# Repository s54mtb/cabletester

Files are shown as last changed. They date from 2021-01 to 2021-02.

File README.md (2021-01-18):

# cabletester, simple cable testing tool

This is simple cable testing tool for checking your cables (e.g. ethernet patch cables or house installation).  Complete tester consists of two modules and tested cable. Master (left) module is on the left. It is connected to the power supply (battery or wall adapter). Slave (right) is passive and has only LEDs. 
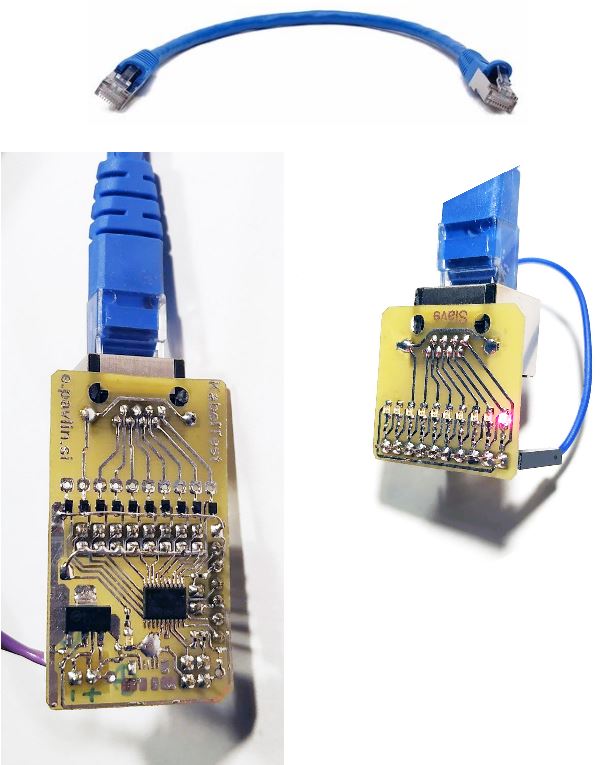
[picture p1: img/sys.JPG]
Cable tester


If cable is OK, the leds should run in ordered sequence: 
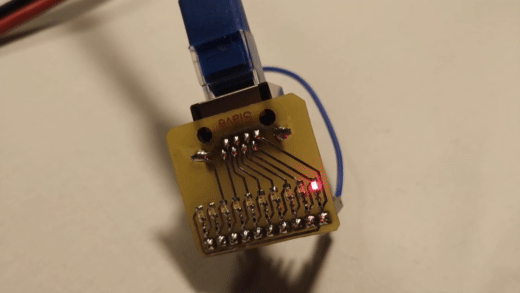
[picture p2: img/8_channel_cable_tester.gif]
LED Sequence


Youtube video: https://youtu.be/-cTYe7WnijU

## Hardware
[Assembly instructions](https://github.com/s54mtb/cabletester/blob/main/HW/AssemblyInstr.md)

### Schematic
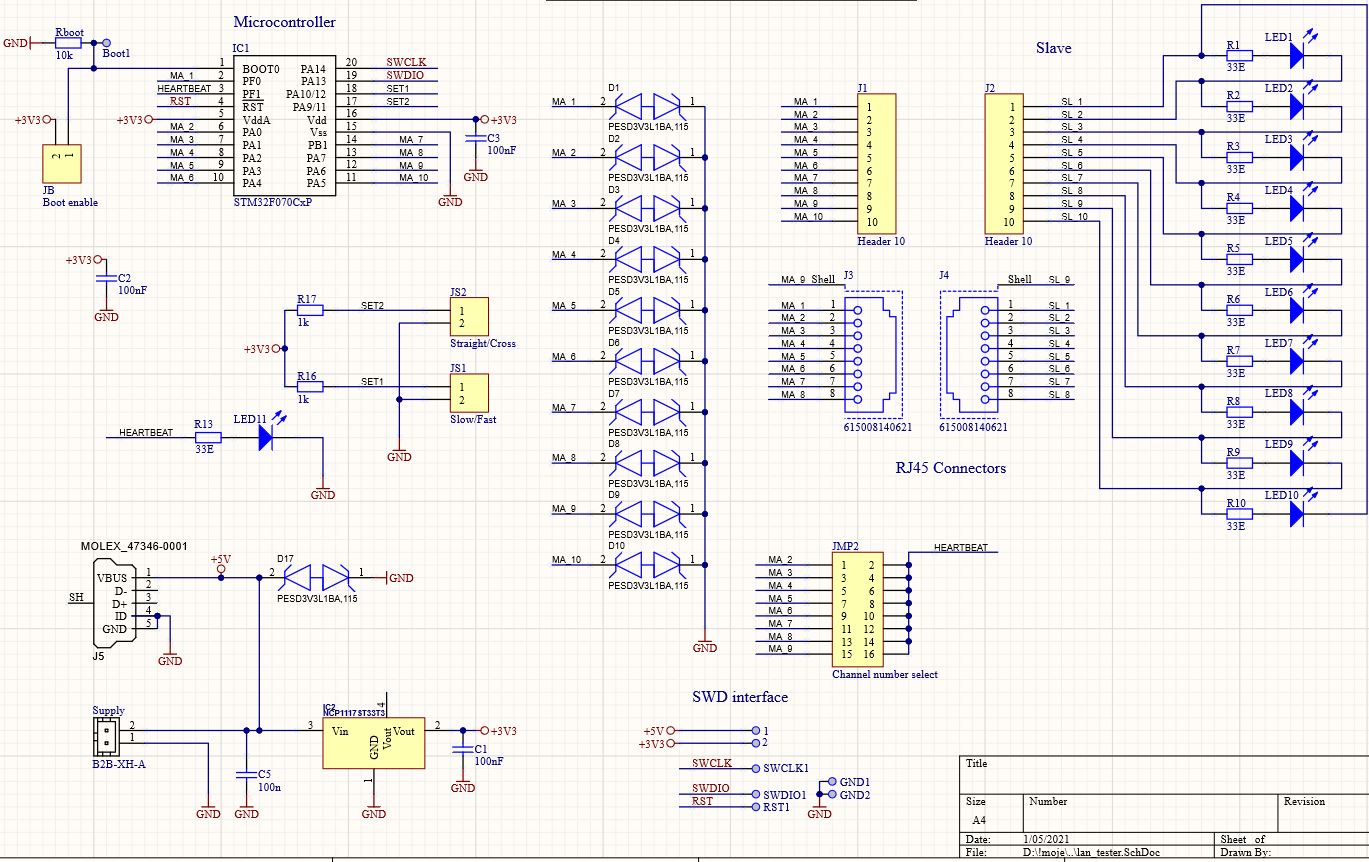
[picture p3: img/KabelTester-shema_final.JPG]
Cable tester schematic


### PCB
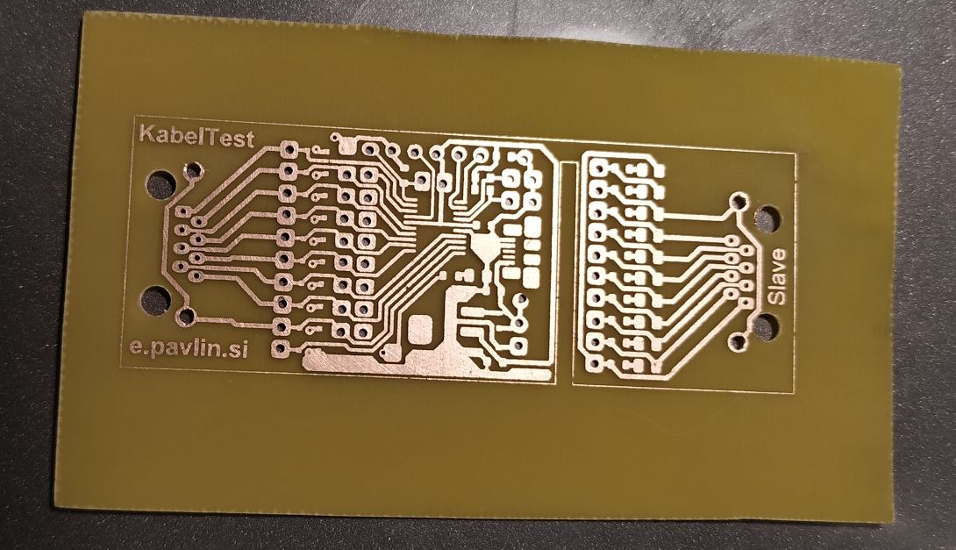
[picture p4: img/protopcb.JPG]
Cable tester single sided PCB


### Artwork for toner transfer PCB
PDF for home made PCB with toner transfer (multiple and single PCB) is available [here](https://github.com/s54mtb/cabletester/blob/main/img/Lantester-tonertransfer.pdf).

## Software
Initial project is prepared with free keil uVision for stm32f0 family.

### Downloading firmware
There is no need to use any IDE or programming adapter to download the firmware. It can be done via serial bootloader. Detailed instructions [are here](https://github.com/s54mtb/cabletester/blob/main/SW/FWdownload.md).

## Housing
Work in progress.

## Operation
There are several jumpers available to control operation of the tester. 

### JS1 - Speed
JS1 selects the speed of sequence. When jumper is attached, the sequence is slow or fast when removed:
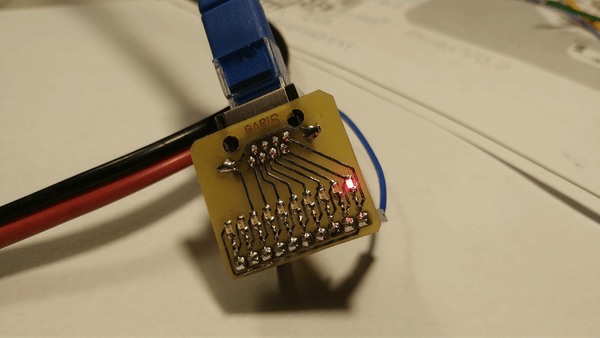
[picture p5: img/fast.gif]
Fast sequence


### JS2 - Cross/straight
JS2 select sequence: When not present the sequence is "normal": Ch1, Ch2, ... Chn. When Jumper is present, the sequnence is set for cross linked cable (useful for testing crosslink patch cables). 

### JMP2 - Channel selection
The cable tester has 10 channels. The channel sequence can ruun from 2 to maximum 10 channels. Jumper JMP2 defines number of channels. Inserted jumper bridge defines where the sequence will stop. When bridge is inserted between pins 13 and 14 (Channel 8), the sequence will run up to 8th channel. Example of the sequence when jumper is placed on channel 5: 

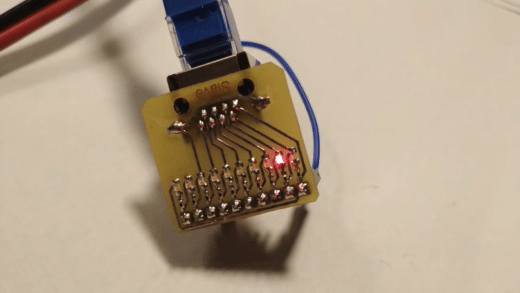
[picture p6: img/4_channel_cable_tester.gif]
5 channels enabled


### Slave settings
PCB for slave device is prepared for RJ45 female connector. There are 10 pins for custom connectors available. When testing less than 10 wires, a jumper must be placed between last+1 channel and first channel to provide proper connection for LEDs.

Example for testing ethernet patch cable (8 channels active): jumper should be placed between pin 1 and pin 9 on the jumper J4 (slave device): 

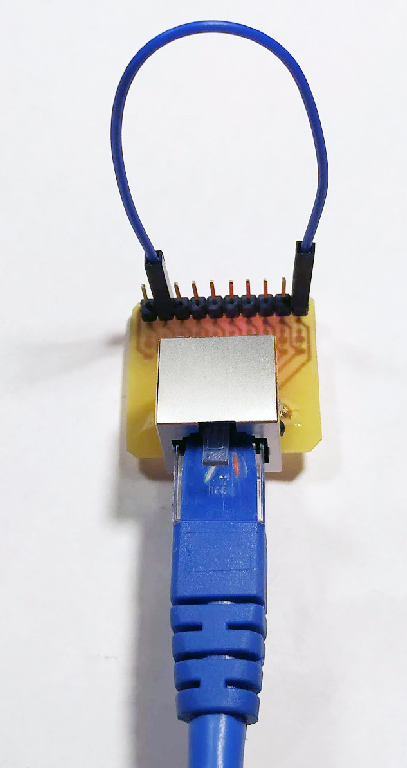
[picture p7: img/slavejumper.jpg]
SlaveJumper


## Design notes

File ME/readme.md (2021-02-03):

# 3D printed housing for this project

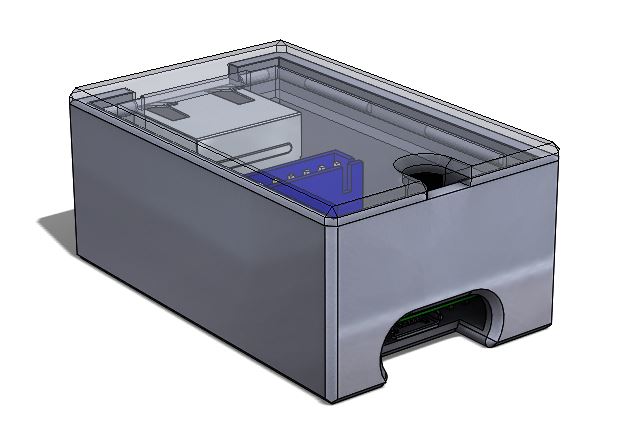
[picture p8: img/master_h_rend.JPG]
Master housing

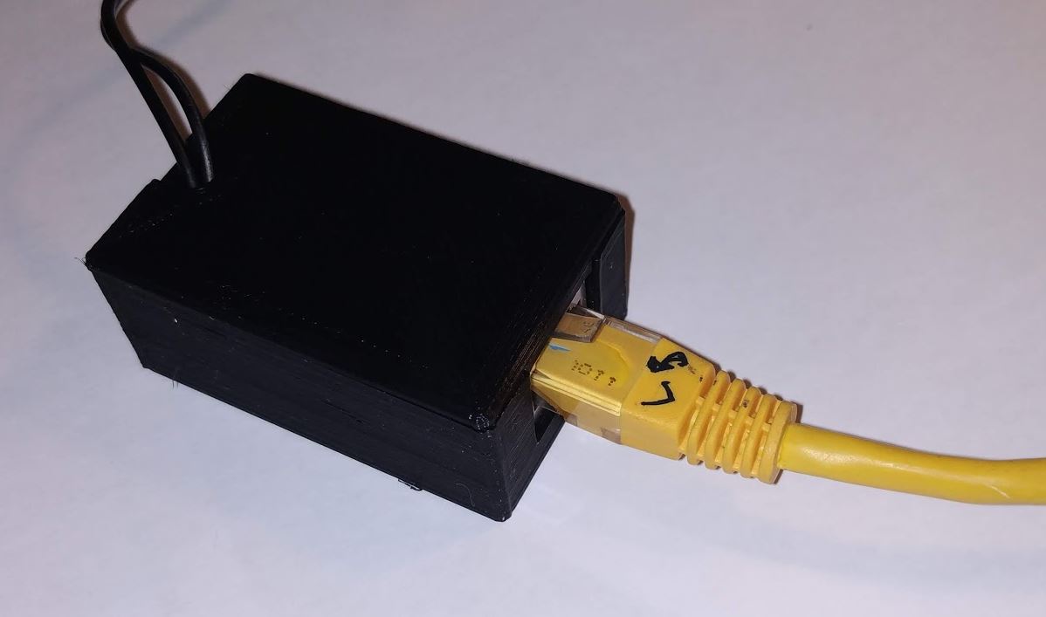
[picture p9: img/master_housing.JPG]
Master housing


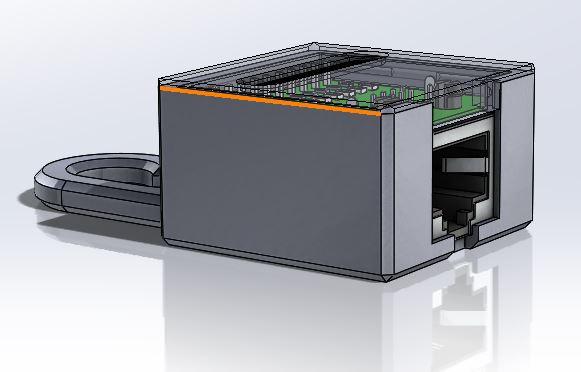
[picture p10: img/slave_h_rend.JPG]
Slave housing

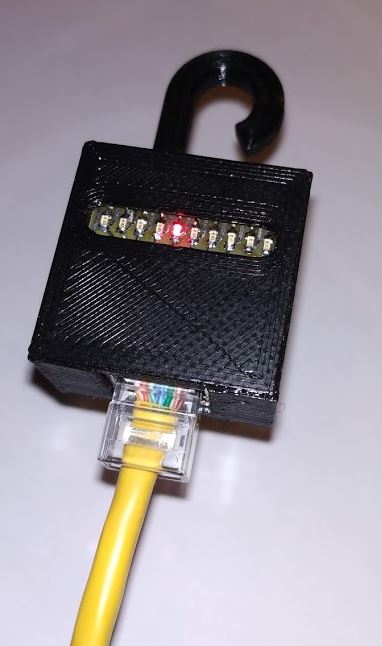
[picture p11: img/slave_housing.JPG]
Slave housing


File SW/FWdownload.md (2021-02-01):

# Downloading firmware
Cable tester has jumpers to enable the bootloader. There is no on-board hardware for downloading the firmware (like arduino) to keep the cost of the device down. 

## Required tools

### Hardware
USB to UART interface is required tool for downloading the firmware. Just make surte it has 3,3V levels. Something like this works fine:

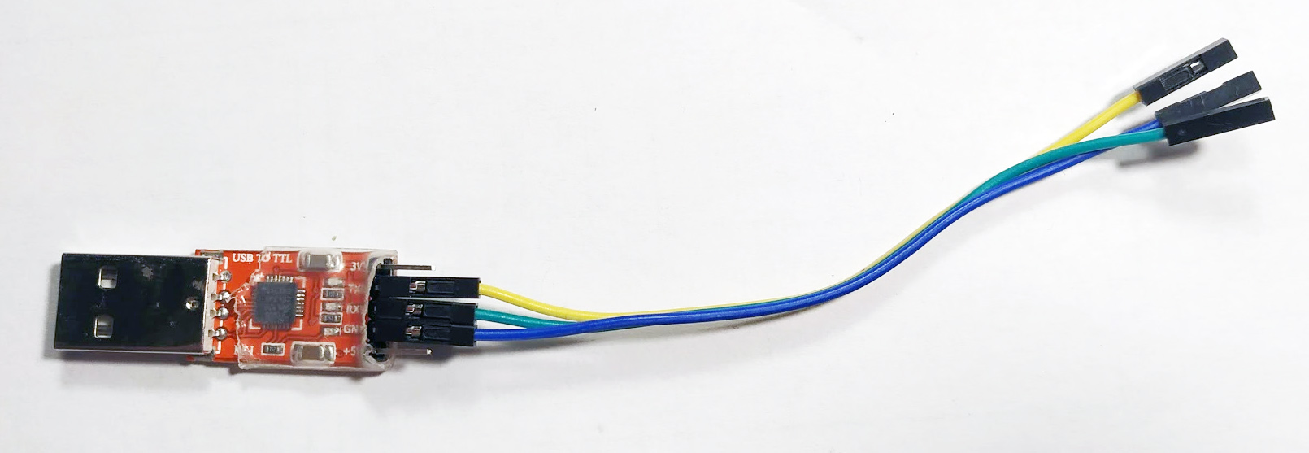
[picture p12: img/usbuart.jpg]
USB to UART interface


### Software
Install STM flash loader demonstrator:  https://www.st.com/en/development-tools/flasher-stm32.html

## Procedure

Remove power supply. Remove all jumpers if placed. 

### Enable bootloader
Place only JB jumper to enable bootloader. 

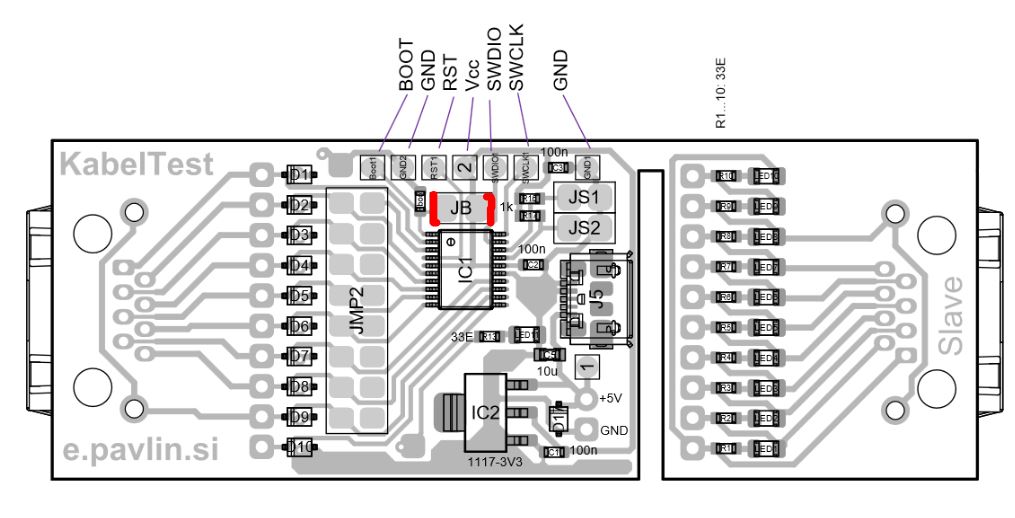
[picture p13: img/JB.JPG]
JB jumper


### Connect serial interface
Three connections are required between USB/UART interface and cable tester: 

* Blue wire: GND
* Green wire (Rx un USB/UART interface), connect to JS2 (PA9/PA11)
* Yellow wire (Tx on USB/UART interface), connect to JS1 (PA10/PA12)

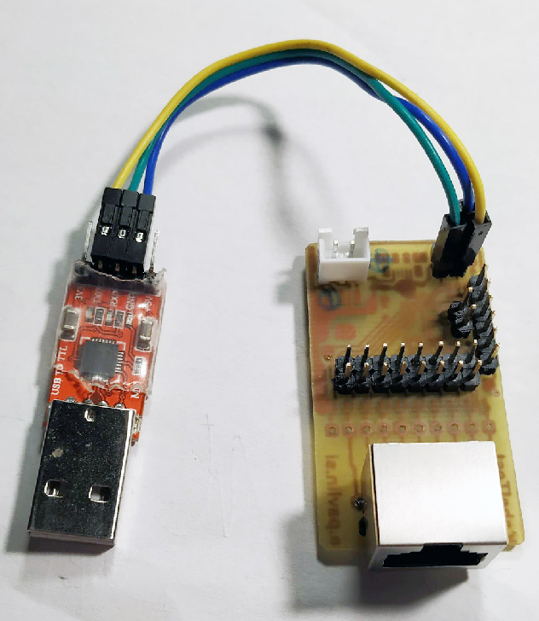
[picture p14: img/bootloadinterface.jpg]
serial connection


Now power-up the circuit and connect serial interface to USB port. 

### Load the software
Run the installed STM32 flasher demonstrator. Select the UART interface: 

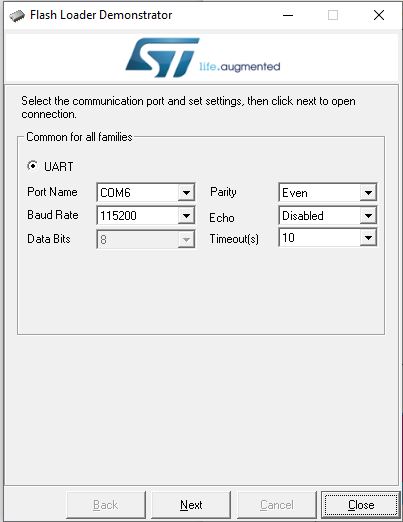
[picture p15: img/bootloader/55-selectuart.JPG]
Select uart


If all is connected and powered up correctly, the application should notice "Target readable": 

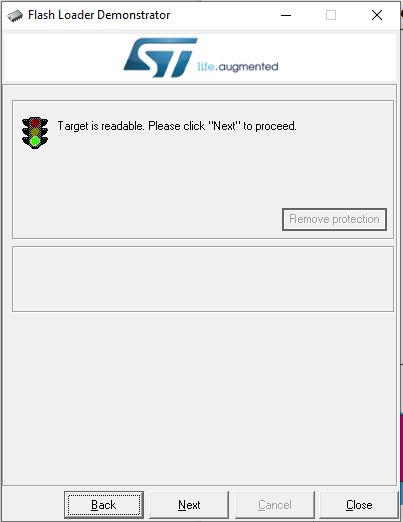
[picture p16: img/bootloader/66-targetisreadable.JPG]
Target readable


Now select the target device: 

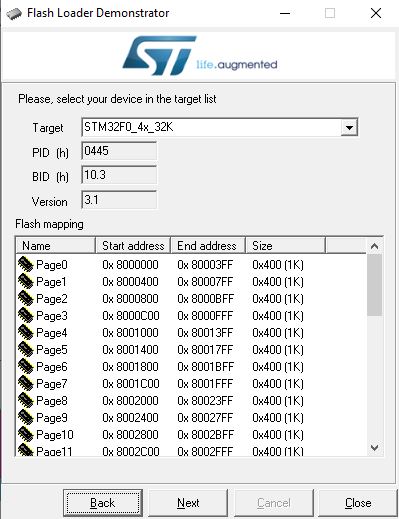
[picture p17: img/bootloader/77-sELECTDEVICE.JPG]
Target device


Select the option "Download to device". Next, select [the hex file](https://raw.githubusercontent.com/s54mtb/cabletester/main/SW/Objects/cabltestr10.hex): 

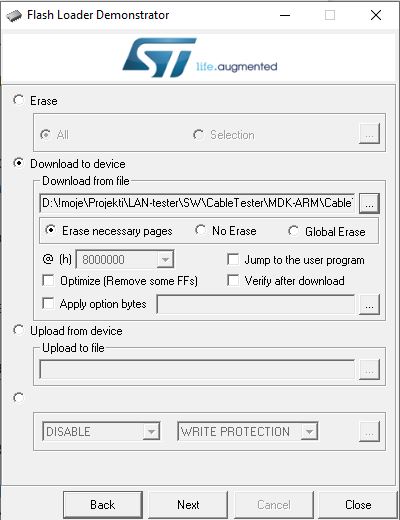
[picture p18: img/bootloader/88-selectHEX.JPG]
Select hex


Hit button "Next". The programming should finish successfully with the notice: 

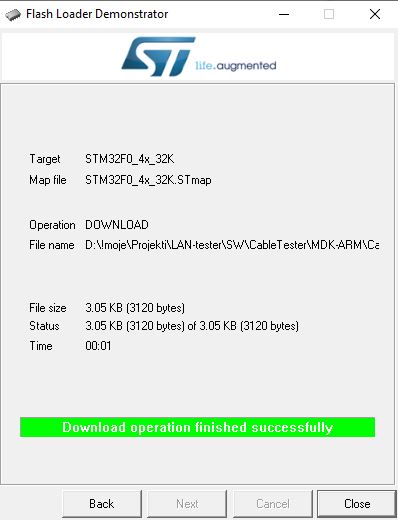
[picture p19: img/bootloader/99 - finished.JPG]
Finished


## Finalize

Remove power from the device. 

Remove jumper JB and UART interface. Place jumper to select the number of channels. 

Power the device, connect the cable and test the operation. 

# Alternative

Use ST-link (integrated on nucleo or discovery board or stand-alone) or any other SWD interface to program via SWD interface. The pinout is shown above. I tested with ST-link, nucleo and U-Link interface with success.

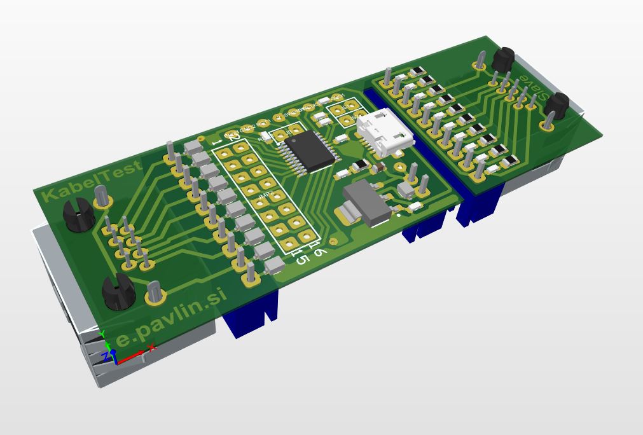
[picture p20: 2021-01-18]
img/pcb-top.JPG

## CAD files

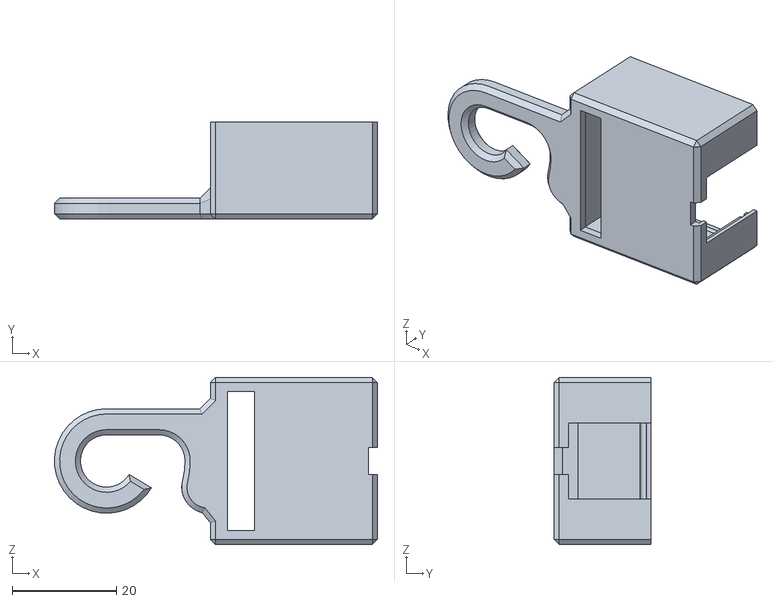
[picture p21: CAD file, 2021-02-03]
ME/slave_bot.STL
61.8 x 18.6 x 32.0

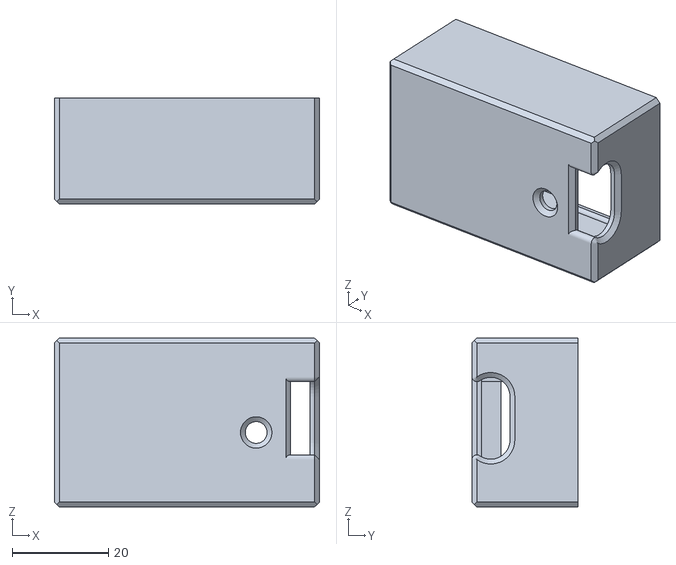
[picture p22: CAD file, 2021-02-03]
ME/master_bot.STL
55.0 x 22.0 x 35.0

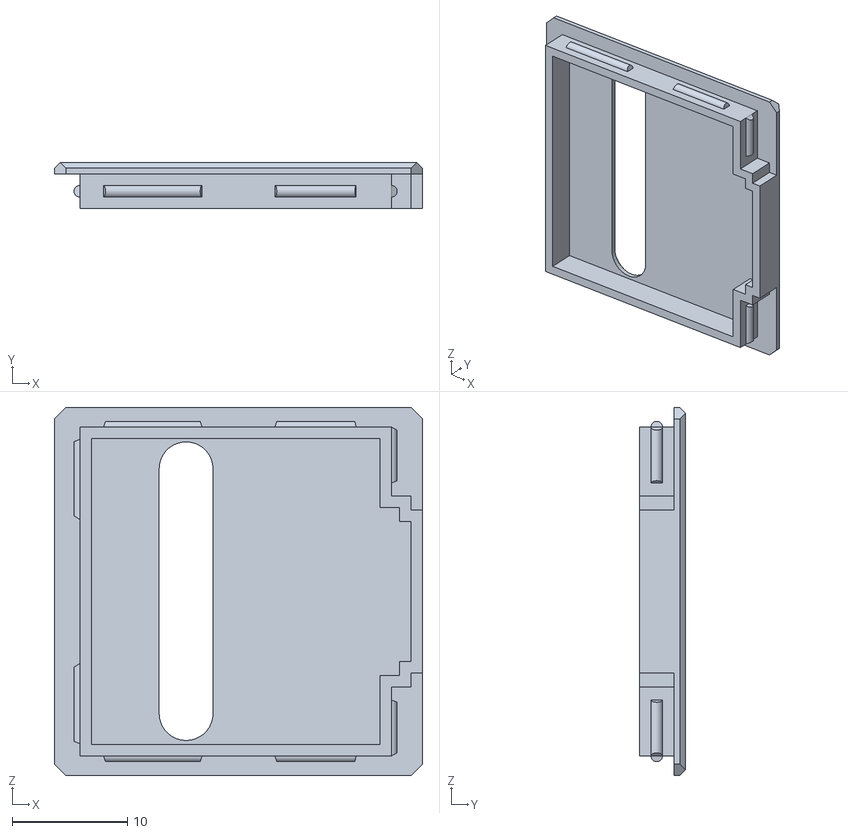
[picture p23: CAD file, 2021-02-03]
ME/slave_top.STL
32.0 x 4.00 x 32.0

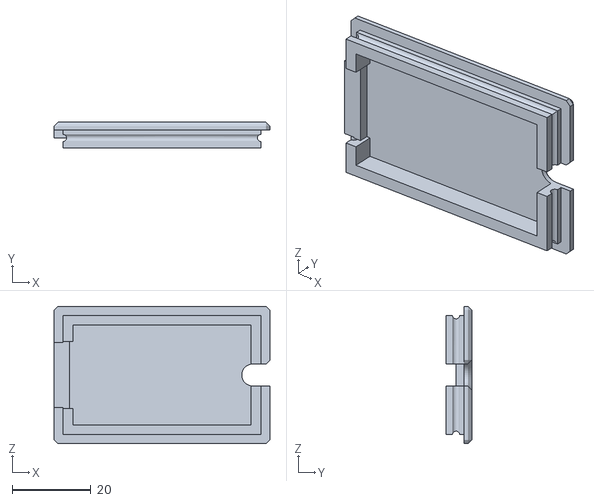
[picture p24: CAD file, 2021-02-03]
ME/master_top.STL
55.0 x 6.50 x 35.0

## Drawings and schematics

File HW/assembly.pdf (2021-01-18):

1

1

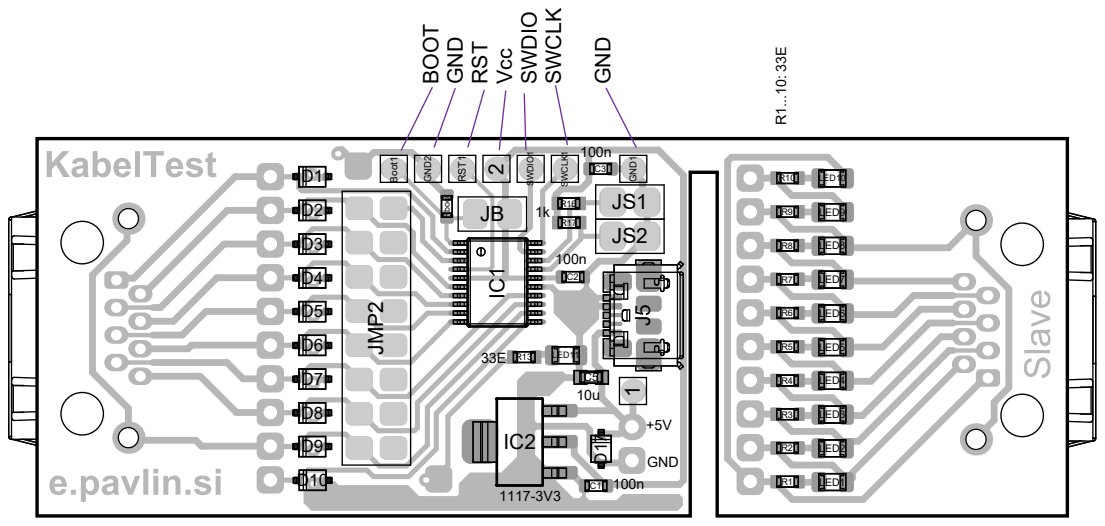
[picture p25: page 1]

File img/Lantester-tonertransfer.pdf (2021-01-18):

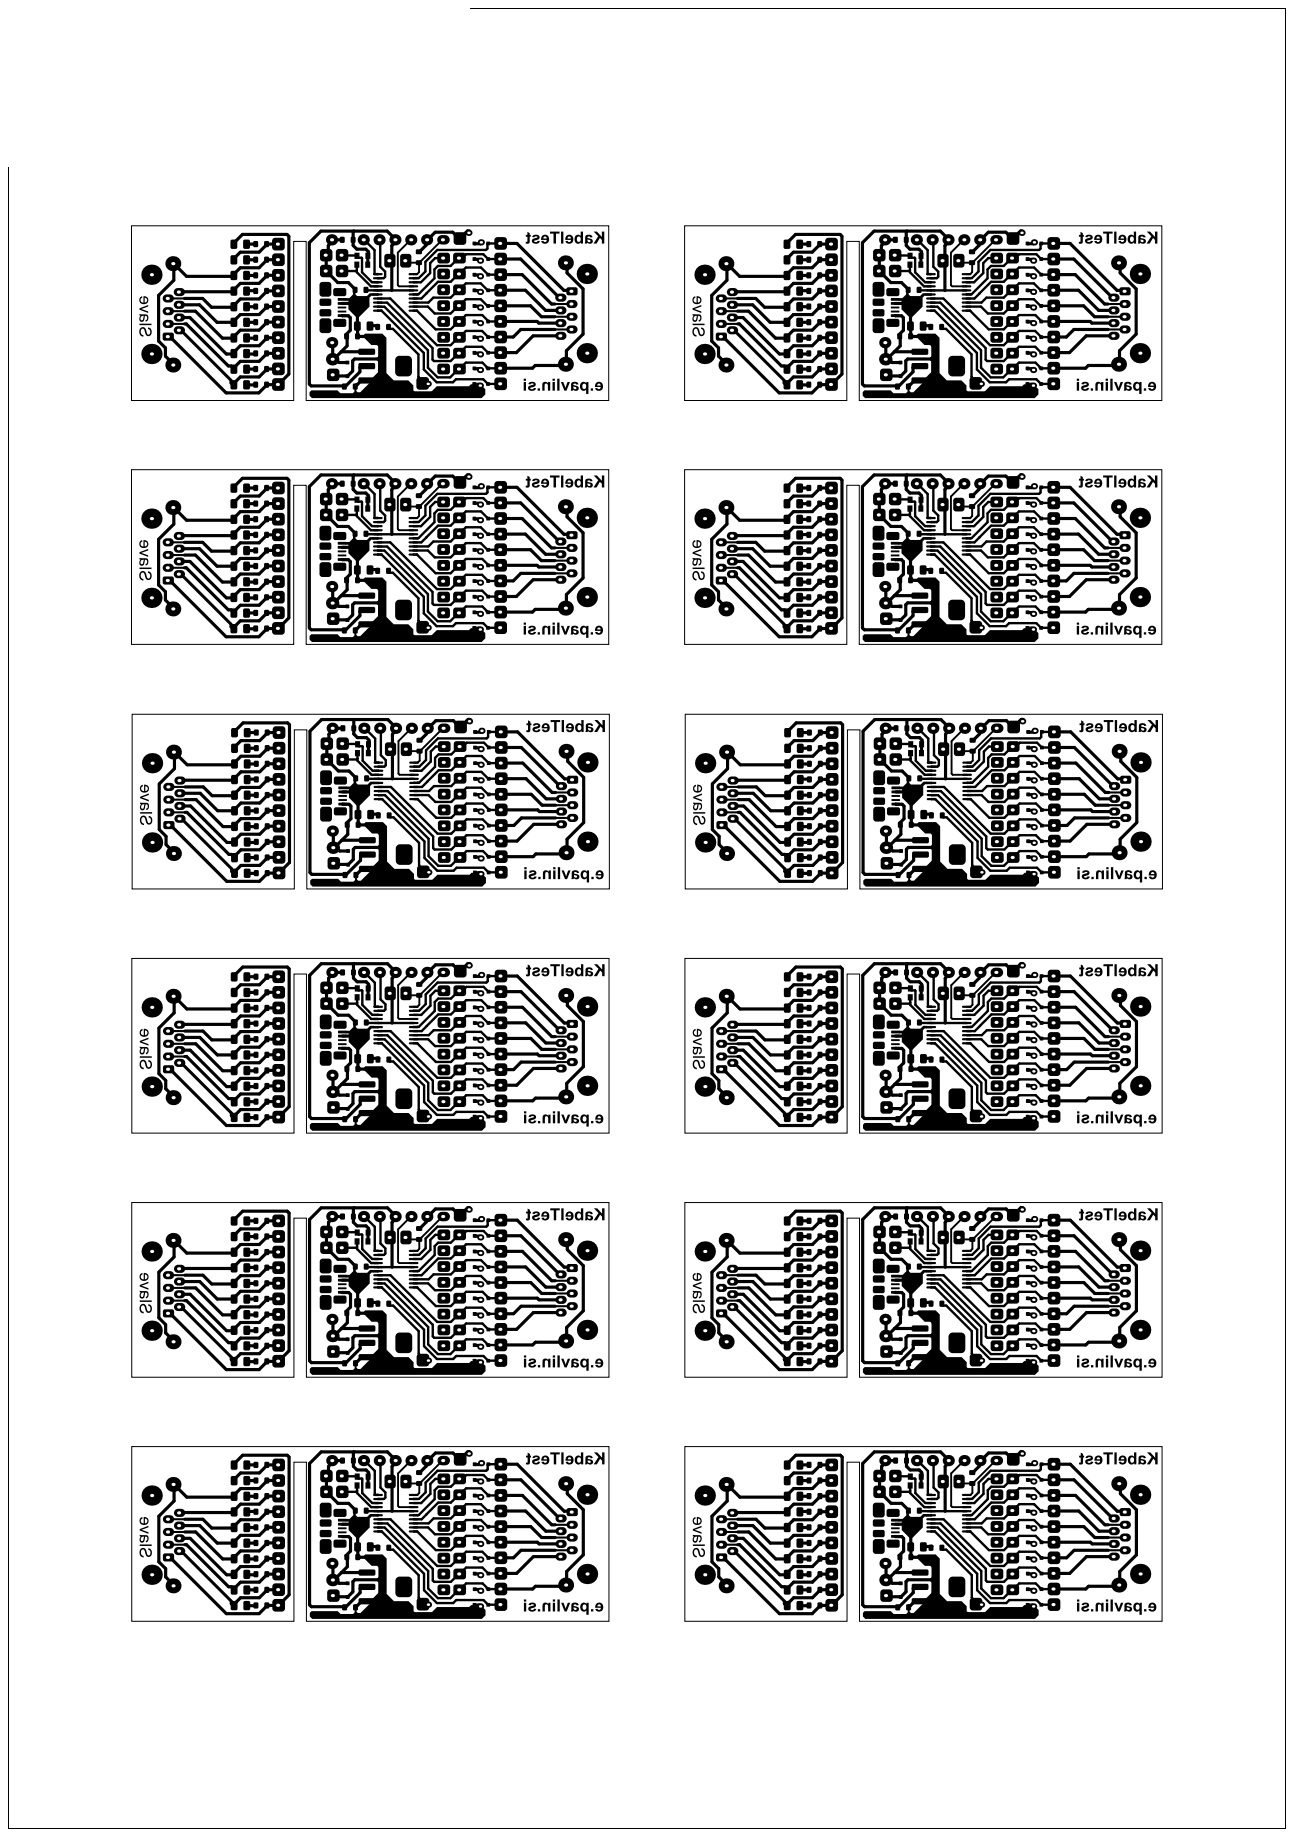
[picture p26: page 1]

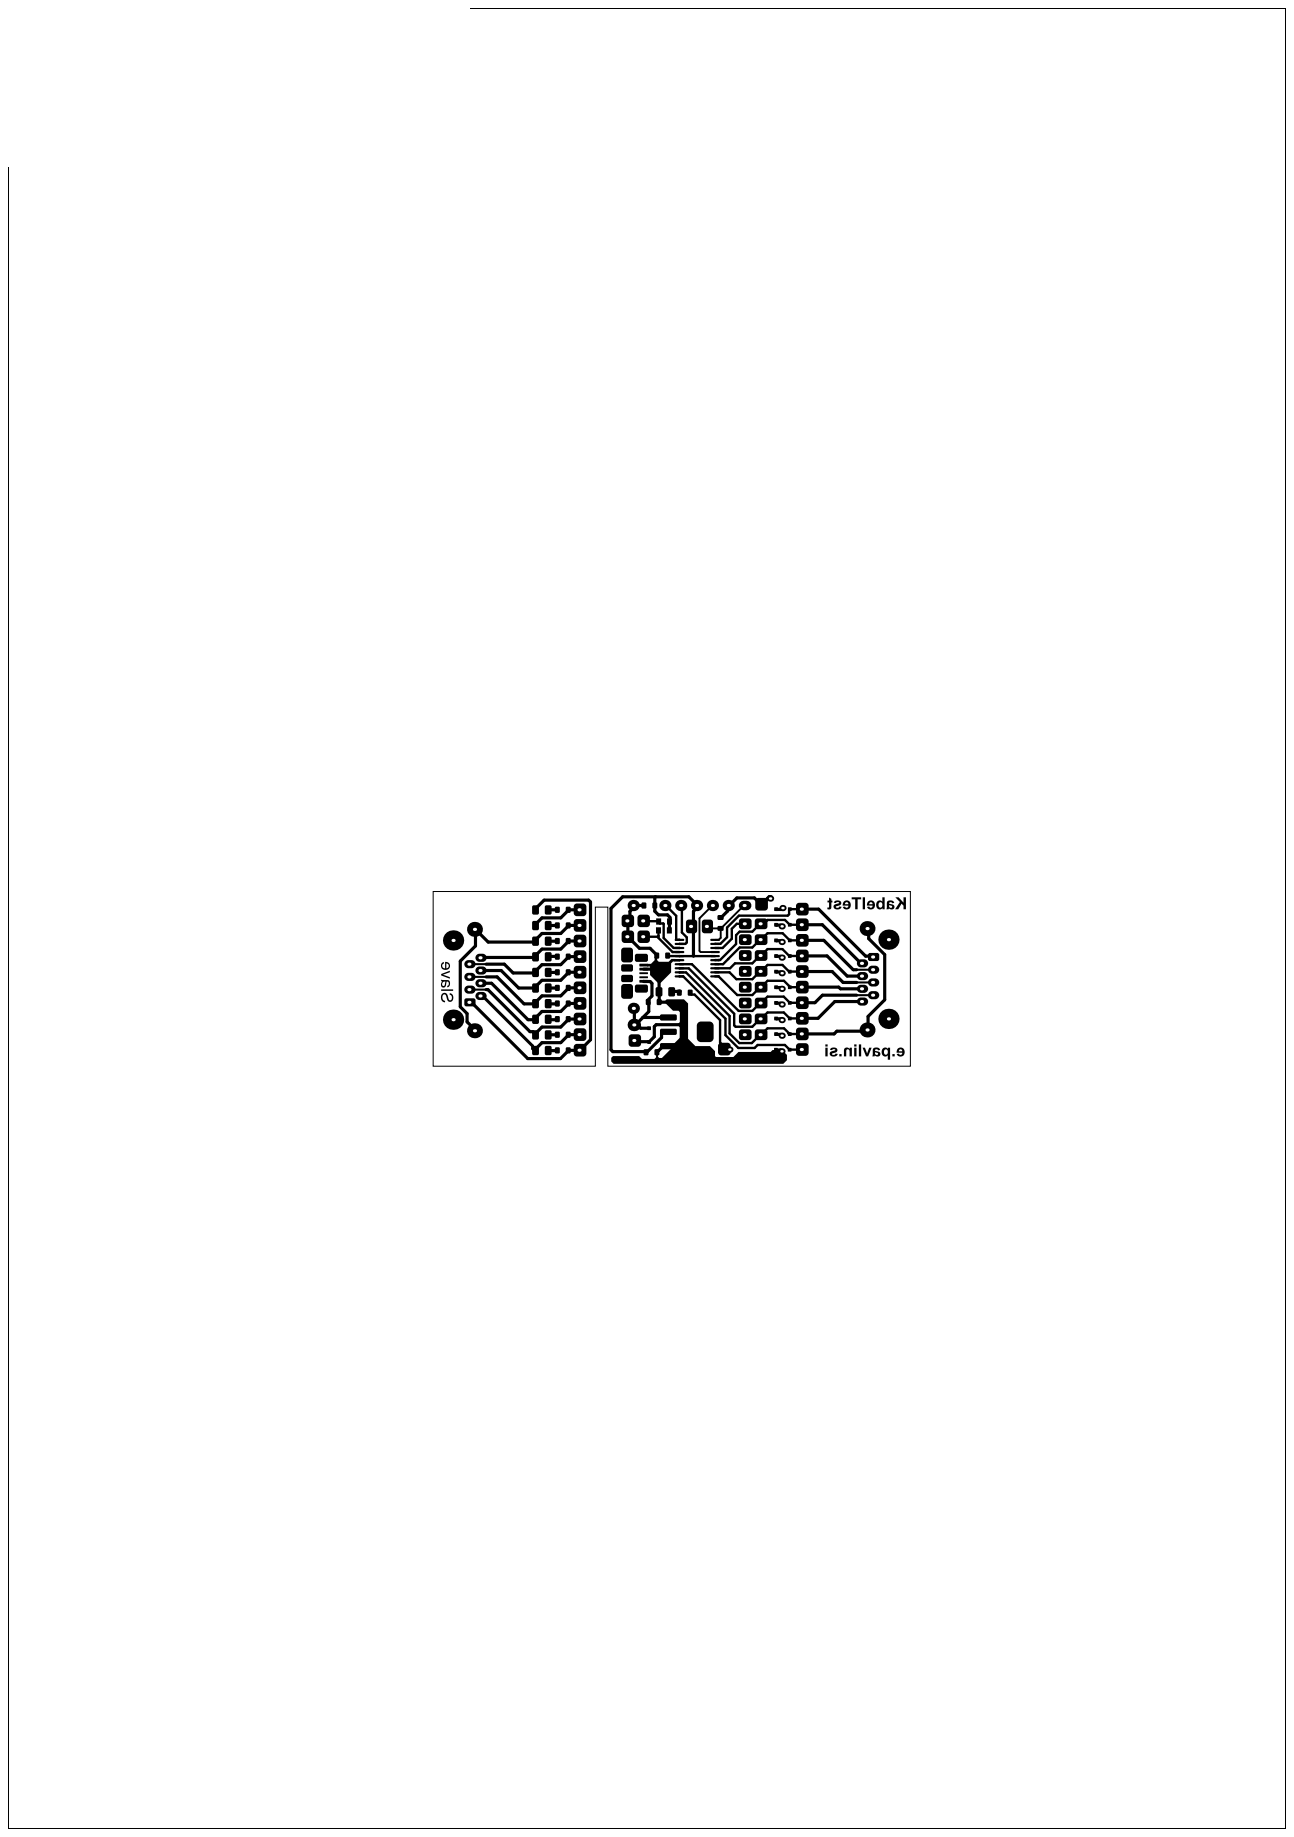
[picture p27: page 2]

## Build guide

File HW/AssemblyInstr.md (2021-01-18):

# Cable tester assembly instructions

## PCB
First make single sided PCB with your favourite toner transfer method

## Assemble PCB
Assembly drawing is [here](https://github.com/s54mtb/cabletester/blob/main/HW/assembly.pdf).

## Additional wire connections
Two wire bridges are required (for single sided PCB): 
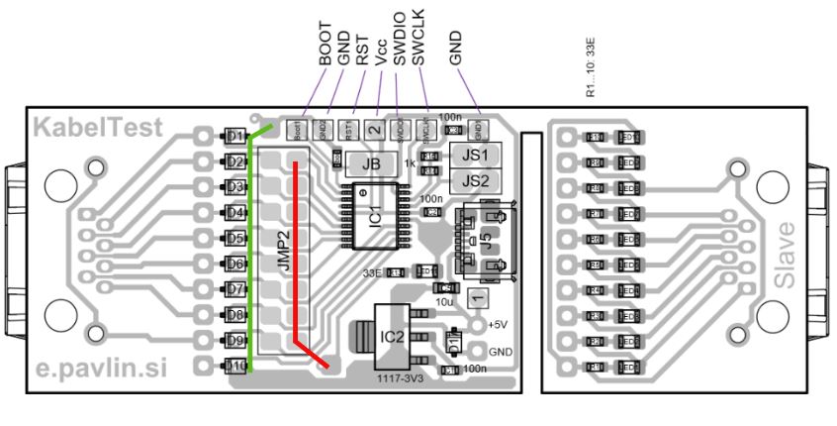
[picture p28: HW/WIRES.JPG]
Two wire bridges


Green connects anodes of the TVS diodes to ground. Red connects selection jumpers to HB signal. 

Finished master module: 
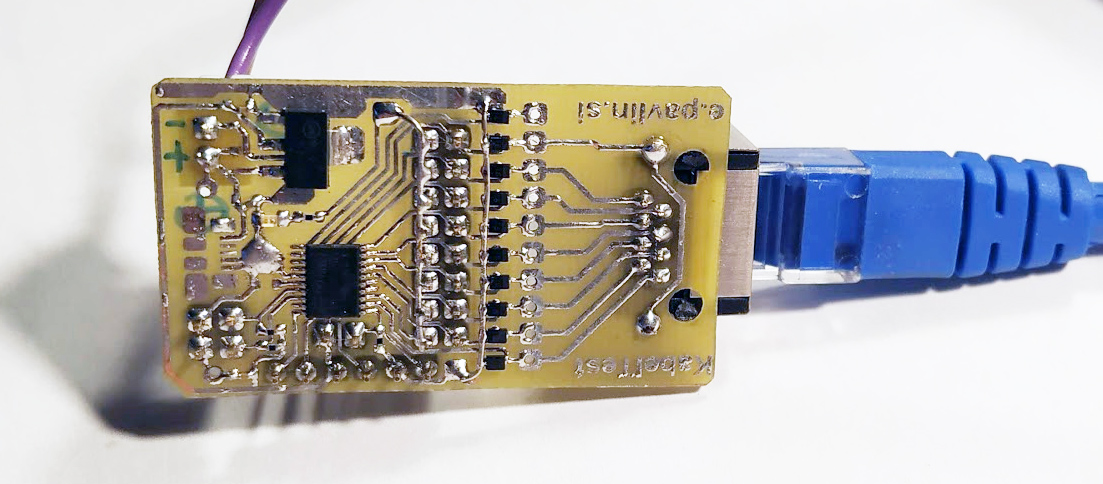
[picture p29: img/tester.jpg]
Finished tester


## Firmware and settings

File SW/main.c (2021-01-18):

/**
  ******************************************************************************
  * @file    Templates/Src/main.c 
  * @author  MCD Application Team
  * @brief   Main program body
  *
  * @note    modified by ARM
  *          The modifications allow to use this file as User Code Template
  *          within the Device Family Pack.
  ******************************************************************************
  * @attention
  *
  * <h2><center>&copy; COPYRIGHT(c) 2016 STMicroelectronics</center></h2>
  *
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
  ******************************************************************************
  */

/* Includes ------------------------------------------------------------------*/
#include "main.h"
#include "leds.h"
#include "settings.H"

#ifdef _RTE_
#include "RTE_Components.h"             // Component selection
#endif
#ifdef RTE_CMSIS_RTOS2                  // when RTE component CMSIS RTOS2 is used
#include "cmsis_os2.h"                  // ::CMSIS:RTOS2
#endif

#ifdef RTE_CMSIS_RTOS2_RTX5
/**
  * Override default HAL_GetTick function
  */
uint32_t HAL_GetTick (void) {
  static uint32_t ticks = 0U;
         uint32_t i;

  if (osKernelGetState () == osKernelRunning) {
    return ((uint32_t)osKernelGetTickCount ());
  }

  /* If Kernel is not running wait approximately 1 ms then increment 
     and return auxiliary tick counter value */
  for (i = (SystemCoreClock >> 14U); i > 0U; i--) {
    __NOP(); __NOP(); __NOP(); __NOP(); __NOP(); __NOP();
    __NOP(); __NOP(); __NOP(); __NOP(); __NOP(); __NOP();
  }
  return ++ticks;
}
#endif

/** @addtogroup STM32F0xx_HAL_Examples
  * @{
  */

/** @addtogroup Templates
  * @{
  */

/* Private typedef -----------------------------------------------------------*/
/* Private define ------------------------------------------------------------*/
/* Private macro -------------------------------------------------------------*/
/* Private variables ---------------------------------------------------------*/
extern settings_t  settings;

/* Private function prototypes -----------------------------------------------*/
static void SystemClock_Config(void);
static void Error_Handler(void);

/* Private functions ---------------------------------------------------------*/

/**
  * @brief  Main program
  * @param  None
  * @retval None
  */
int main(void)
{
	
  /* STM32F0xx HAL library initialization:
       - Configure the Flash prefetch
       - Systick timer is configured by default as source of time base, but user 
         can eventually implement his proper time base source (a general purpose 
         timer for example or other time source), keeping in mind that Time base 
         duration should be kept 1ms since PPP_TIMEOUT_VALUEs are defined and 
         handled in milliseconds basis.
       - Low Level Initialization
     */
  HAL_Init();

  /* Configure the system clock to have a system clock = 48 Mhz */
  SystemClock_Config();
  SystemCoreClockUpdate();


  /* Init LEDS */
	LED_Init();

#ifdef RTE_CMSIS_RTOS2
  /* Initialize CMSIS-RTOS2 */
  osKernelInitialize ();

  /* Create thread functions that start executing, 
  Example: osThreadNew(app_main, NULL, NULL); */

  /* Start thread execution */
  osKernelStart();
#endif


  /* Infinite loop */
  while (1)
  {
		CheckSettings();
		for (int i=0; i<10; i++) {
			if (LED_Enabled (i+1) ) {
				BlinkHB((settings.mode == 0) ? 50 : 10);
				Main_Led(i+1);
				HAL_Delay((settings.mode == 0) ? 200 : 20);
			}
		}
  }
}

/**
  * @brief  System Clock Configuration
  *         The system Clock is configured as follow : 
  *            System Clock source            = PLL (HSI)
  *            SYSCLK(Hz)                     = 48000000
  *            HCLK(Hz)                       = 48000000
  *            AHB Prescaler                  = 1
  *            APB1 Prescaler                 = 1
  *            HSI Frequency(Hz)              = 8000000
  *            PREDIV                         = 1
  *            PLLMUL                         = 6
  *            Flash Latency(WS)              = 1
  * @param  None
  * @retval None
  */
static void SystemClock_Config(void)
{
  RCC_ClkInitTypeDef RCC_ClkInitStruct;
  RCC_OscInitTypeDef RCC_OscInitStruct;
  
  /* No HSE Oscillator on Nucleo, Activate PLL with HSI as source */
  RCC_OscInitStruct.OscillatorType = RCC_OSCILLATORTYPE_NONE;
  RCC_OscInitStruct.PLL.PLLState = RCC_PLL_ON;
  RCC_OscInitStruct.PLL.PLLSource = RCC_PLLSOURCE_HSI;
  RCC_OscInitStruct.PLL.PREDIV = RCC_PREDIV_DIV1;
  RCC_OscInitStruct.PLL.PLLMUL = RCC_PLL_MUL6;
  if (HAL_RCC_OscConfig(&RCC_OscInitStruct)!= HAL_OK)
  {
    Error_Handler();
  }

  /* Select PLL as system clock source and configure the HCLK, PCLK1 clocks dividers */
  RCC_ClkInitStruct.ClockType = (RCC_CLOCKTYPE_SYSCLK | RCC_CLOCKTYPE_HCLK | RCC_CLOCKTYPE_PCLK1);
  RCC_ClkInitStruct.SYSCLKSource = RCC_SYSCLKSOURCE_PLLCLK;
  RCC_ClkInitStruct.AHBCLKDivider = RCC_SYSCLK_DIV1;
  RCC_ClkInitStruct.APB1CLKDivider = RCC_HCLK_DIV1;
  if (HAL_RCC_ClockConfig(&RCC_ClkInitStruct, FLASH_LATENCY_1)!= HAL_OK)
  {
    Error_Handler();
  }
}

/**
  * @brief  This function is executed in case of error occurrence.
  * @param  None
  * @retval None
  */
static void Error_Handler(void)
{
  /* User may add here some code to deal with this error */
  while(1)
  {
  }
}

#ifdef  USE_FULL_ASSERT

/**
  * @brief  Reports the name of the source file and the source line number
  *         where the assert_param error has occurred.
  * @param  file: pointer to the source file name
  * @param  line: assert_param error line source number
  * @retval None
  */
void assert_failed(char* file, uint32_t line)
{ 
  /* User can add his own implementation to report the file name and line number,
     ex: printf("Wrong parameters value: file %s on line %d\r\n", file, line) */

  /* Infinite loop */
  while (1)
  {
  }
}
#endif

/**
  * @}
  */

/**
  * @}
  */

/************************ (C) COPYRIGHT STMicroelectronics *****END OF FILE****/

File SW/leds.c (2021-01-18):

#include "stm32f0xx_hal.h"              // Keil.Standalone::Device:STM32Cube HAL:COMMON
#include "main.h" 
#include "leds.h"

/*
LEDs init 

Leds are placed as follows: 

	CH1  PF0
	CH2  PA0
	CH3  PA1
	CH4  PA2
	CH5  PA3
	CH6  PA4
	CH7  PB1
	CH8  PA7
	CH9  PA6
	CH10 PA5

*/

 GPIO_TypeDef 
	           *chx[10] = { MA1_GPIO_Port, 
                          MA2_GPIO_Port, 
                          MA3_GPIO_Port, 
                          MA4_GPIO_Port, 
                          MA5_GPIO_Port, 
                          MA6_GPIO_Port, 
                          MA7_GPIO_Port, 
                          MA8_GPIO_Port,
                          MA9_GPIO_Port,
                          MA10_GPIO_Port,
						           };
						 
const uint16_t 
	            chp[10] = { MA1_Pin, 
                          MA2_Pin, 
                          MA3_Pin, 
                          MA4_Pin, 
                          MA5_Pin, 
                          MA6_Pin, 
                          MA7_Pin, 
                          MA8_Pin,
                          MA9_Pin,
                          MA10_Pin
							          };


void LED_Init(void) {
	__HAL_RCC_GPIOA_CLK_ENABLE();
  __HAL_RCC_GPIOB_CLK_ENABLE();
  __HAL_RCC_GPIOF_CLK_ENABLE();

	GPIO_InitTypeDef	LEDsGPIO_InitStruct = {0};
	
  LEDsGPIO_InitStruct.Mode = GPIO_MODE_OUTPUT_PP;
  LEDsGPIO_InitStruct.Pull = GPIO_PULLUP;
  LEDsGPIO_InitStruct.Speed = GPIO_SPEED_FREQ_LOW;
	
	for (int i=0; i<10; i++) {
		LEDsGPIO_InitStruct.Pin = chp[i];
		HAL_GPIO_Init(chx[i], &LEDsGPIO_InitStruct);
		HAL_GPIO_WritePin(chx[i], chp[i], GPIO_PIN_RESET);
	}
	
	for (int i=0; i<10; i++) {
		LEDsGPIO_InitStruct.Pin = chp[i];
		HAL_GPIO_Init(chx[i], &LEDsGPIO_InitStruct);
		HAL_GPIO_WritePin(chx[i], chp[i], GPIO_PIN_RESET);
	}

	/* HB pin set to input to avoid fantom blinking via setting jumpers */
  LEDsGPIO_InitStruct.Mode = GPIO_MODE_INPUT;
	LEDsGPIO_InitStruct.Pin = HB_Pin;
	HAL_GPIO_Init(HB_GPIO_Port, &LEDsGPIO_InitStruct);
	HAL_GPIO_WritePin(HB_GPIO_Port, HB_Pin, GPIO_PIN_RESET);

}


/** Set all LED pins to input mode */
void LED_AllInputs(void) {
  GPIO_InitTypeDef	LEDsGPIO_InitStruct = {0};
  LEDsGPIO_InitStruct.Mode = GPIO_MODE_INPUT;
	for (int i=0; i<10; i++) {
		LEDsGPIO_InitStruct.Pin = chp[i];
		HAL_GPIO_Init(chx[i], &LEDsGPIO_InitStruct);
		HAL_GPIO_WritePin(chx[i], chp[i], GPIO_PIN_RESET);
	}	
}	



/** Set heartbit LED */
void HB_LED(GPIO_PinState state) {
	HAL_GPIO_WritePin(HB_GPIO_Port, HB_Pin, state);
}

/** set single LED output to 1, other 0
    num: 1...10, other set all to 0
*/
void Main_Led(uint8_t num)	{
  for (int i=0; i<10; i++) {
			HAL_GPIO_WritePin(chx[i], chp[i], GPIO_PIN_RESET);
	}	
	if ((num>0) & (num<11)) {	
		num--;
	  HAL_GPIO_WritePin(chx[num], chp[num], GPIO_PIN_SET);
	}
}


/** Blink HB LED */
void BlinkHB(uint32_t pulse) {
  GPIO_InitTypeDef	LEDsGPIO_InitStruct = {0};
	LED_AllInputs();

  LEDsGPIO_InitStruct.Mode = GPIO_MODE_OUTPUT_PP;
  LEDsGPIO_InitStruct.Pull = GPIO_PULLUP;
  LEDsGPIO_InitStruct.Speed = GPIO_SPEED_FREQ_LOW;
	LEDsGPIO_InitStruct.Pin = HB_Pin;
	HAL_GPIO_Init(HB_GPIO_Port, &LEDsGPIO_InitStruct);
	
	HB_LED(GPIO_PIN_SET);
	HAL_Delay(pulse);
	
	
  LED_Init();



}

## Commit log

2021-01-18 Added wires assembly drawing
2021-01-18 Assembly instructions.
2021-01-18 USB UART interface image
2021-02-03 Housing files added
    [master_bot.STL, master_top.STL, slave_bot.STL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]
